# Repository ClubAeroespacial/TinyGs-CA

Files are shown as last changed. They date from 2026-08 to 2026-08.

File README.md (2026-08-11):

# Placa ESP32-C3 + SX1278 (LoRa 433 MHz) — Version2

Bring-up y validación de la revisión **Version2** de la placa.
Módulos: **ESP32-C3-WROOM-02-N4** (4 MB) + módulo **SX1278** de 433 MHz con conector u.FL.

**Estado: hardware validado.** 5 unidades fabricadas (3 + 2), todas funcionando.
Enlace LoRa bidireccional confirmado entre dos placas.

---

## Pinout

Verificado de dos formas independientes: extraído del netlist de KiCad
(`Version2.kicad_pcb`) y confirmado con firmware que corre en la placa.

| Señal | GPIO | Pad del módulo | Nota |
|---|---|---|---|
| LoRa SCK | **10** | 10 | |
| LoRa MISO | **6** | 5 | |
| LoRa MOSI | **7** | 6 | |
| LoRa NSS | **8** | 7 | strapping pin — ver ERRATA #4 |
| LoRa RESET | **5** | 4 | |
| LoRa DIO0 | **4** | 3 | conectado, permite usar interrupciones |
| UART TX | **21** | 12 | compartido con el LED — ver ERRATA #1 |
| UART RX | **20** | 11 | |
| Botón RESET | EN | 2 | |
| Botón BOOT | **0** | 18 | no es strapping pin — ver ERRATA #2 |
| Pull-up 10k (R10) | 2 | 16 | strapping, correcto |
| Pull-up 10k (R11) | 8 | 7 | strapping, correcto |

**GPIO libres:** 1, 3, 9, 18, 19
**DIO1–DIO5 del SX1278:** sin conectar

```cpp
#define PIN_SCK   10
#define PIN_MISO   6
#define PIN_MOSI   7
#define PIN_NSS    8
#define PIN_RST    5
#define PIN_DIO0   4
```

---

## Estado de validación

| Qué | Estado | Evidencia |
|---|---|---|
| Regulador 3.3 V (AMS1117) | OK | 3.3 V medidos, sin cortos |
| Arranque del ESP32-C3 | OK | mensaje de la ROM en UART |
| Flash 4 MB | OK | `flash-id` y sketches corriendo |
| UART bidireccional | OK | consola + flasheo exitoso |
| Modo programación | OK | `boot:0x5 (DOWNLOAD(USB/UART0/1))` |
| WiFi + estabilidad de fuente | OK | 6 redes, sin brownout en el pico de ~350 mA |
| SPI hacia el SX1278 | OK | `RegVersion = 0x12` estable |
| **Enlace LoRa bidireccional** | **OK** | PING/PONG entre 2 placas y test 14 del banco |
| **Test de producción completo** | **OK** | **14/14** en las unidades probadas |

Valores de referencia de placa sana: WiFi **-48 a -51 dBm** con 10-14 redes,
piso de ruido LoRa **-123 dBm**, frecuencia por defecto **434.0 MHz**.
Ver la tabla completa en [ERRATA.md](ERRATA.md).

### Todavía sin validar

- Alcance real (requiere antenas u.FL → SMA, aún no disponibles)
- Consumo en régimen y a batería
- Comportamiento térmico bajo carga sostenida

> **Nota sobre el -124 dBm:** la sensibilidad del SX1278 en SF7/BW125 es -123 dBm.
> El enlace funcionó **en el límite físico del chip**, sin antena y a 2 dBm, con
> ~8% de paquetes exitosos. Eso no es una falla: es el resultado esperado con los
> conectores u.FL al aire. Con antenas se espera -40 a -50 dBm a corta distancia.

---

## Cómo flashear

El programador usado es un **PL2303 sin DTR/RTS**, así que el modo descarga se
entra a mano.

### Cableado (TX y RX van cruzados)

```
PL2303              J2
------              --------------
GND     --------->  GND   (pin 1)
+5V     --------->  5V    (pin 2)
RXD     <---------  TX    (pin 3)
TXD     --------->  RX    (pin 4)
(nada)              RST   (pin 5)
(nada)              DTR   (pin 6)
```

### Configuración de Arduino IDE

| Opción | Valor |
|---|---|
| Board | ESP32C3 Dev Module |
| **USB CDC On Boot** | **Disabled** |
| Flash Mode | DIO |
| Flash Size | 4MB (32Mb) |
| Upload Speed | 921600 (probado y estable) |

### Secuencia

```
1. Mantener BOOT apretado
2. Apretar y soltar RESET
3. Soltar BOOT
4. Verificar en el monitor: boot:0x... (DOWNLOAD(USB/UART0/1))
5. Cerrar el Monitor Serie
6. Upload
7. Apretar RESET a mano (no hay RTS conectado)
```

**Indicador infalible:** el `boot:0x...` del mensaje de arranque.
`DOWNLOAD` = listo para flashear. `SPI_FAST_FLASH_BOOT` = no entraste.

---

## Sketches

| Carpeta | Qué prueba | Cuándo usarlo |
|---|---|---|
| `00_test_produccion/` | **14 pruebas automáticas con veredicto APROBADA / RECHAZADA** y línea CSV para planilla | **El de todos los días.** Es el banco de pruebas del lote. Ver la calibración de umbrales en ERRATA.md antes de correr una tanda |
| `04_test_lucas/` | Lee `RegVersion` del SX1278 por SPI | Primer test de una placa nueva si querés algo mínimo. 70 líneas, sin librerías |
| `01_smoke_test/` | CPU, flash, UART, LED, escaneo de WiFi | Validación general. El escaneo de WiFi es el que fuerza el pico de 350 mA y detecta problemas de fuente |
| `05_buscar_led/` | Versión corta del anterior | Cuando solo querés el estrés de fuente sin todo lo demás |
| `02_scan_sx1278/` | Encuentra los pines SPI por fuerza bruta | Si alguna vez hay una revisión nueva y no se conoce el pinout. Con el comando `v` verifica un pinout conocido en 2 segundos |
| `03_lora_pingpong/` | **Enlace de radio real entre 2 placas** | El único test que valida el amplificador, el cristal y el camino de antena |

> `04_test_lucas.ino` está **sin modificar**, tal como fue escrito originalmente.
> Se conserva así a propósito: es la referencia contra la que se comparó todo lo demás.

### Ping-pong: cómo se corre

El **mismo sketch** va en las dos placas. Las dos arrancan como RESPONDEDOR.
En la que tiene consola se manda `a` y pasa a EMISOR.

```
a  -> pasar a EMISOR        s  -> estadísticas
b  -> pasar a RESPONDEDOR   r  -> medir piso de ruido
t<n> -> potencia TX (2-17)  f<n> -> spreading factor (7-12)
d  -> cazar el pin DIO0
```

**Sin antena: 2 dBm y las placas a 5-10 cm.** No subir la potencia: el PA se
degrada transmitiendo contra un circuito abierto, y la degradación es silenciosa.

---

## Documentos

- **[ERRATA.md](ERRATA.md)** — los 7 defectos encontrados y qué cambiar en la v2
- **[00_GUIA_BRINGUP.md](00_GUIA_BRINGUP.md)** — guía completa de bring-up con mediciones
- **[PASOS_TEST_LUCAS.md](PASOS_TEST_LUCAS.md)** — procedimiento paso a paso con hitos

---

## Pendientes

- [ ] Comprar pigtails u.FL → SMA y antenas de 433 MHz (×5)
- [ ] Medir alcance real al aire libre
- [ ] Adaptador USB-TTL con DTR/RTS (CP2102 o CH340) para reset automático
- [ ] Regenerar los gerbers desde Version2 — ver ERRATA #7
- [ ] Aplicar los cambios de ERRATA.md a la v3

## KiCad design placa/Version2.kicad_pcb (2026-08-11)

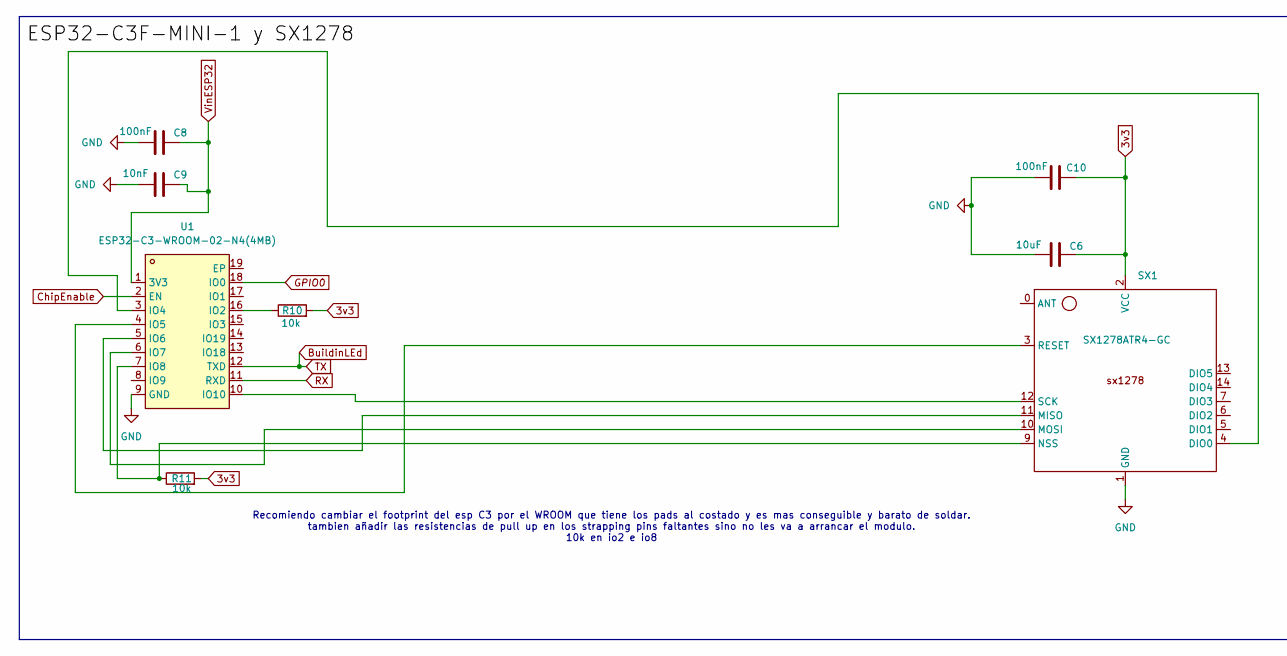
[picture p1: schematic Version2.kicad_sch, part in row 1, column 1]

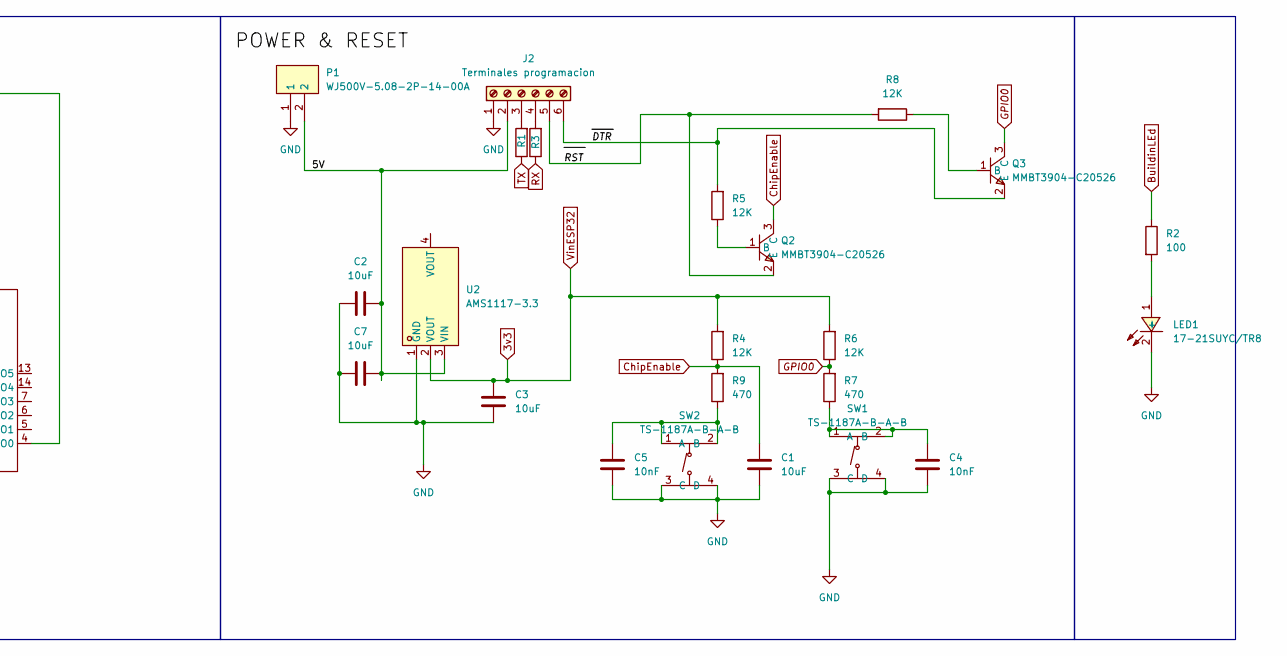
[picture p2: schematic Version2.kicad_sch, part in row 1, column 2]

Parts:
C1, C2, C3, C6, C7: 10uF; C_0805_2012Metric
C4, C5, C9: 10nF; C_0402_1005Metric
C8, C10: 100nF; C_0402_1005Metric
J2: Terminales programacion; PinHeader_1x06_P2.54mm_Vertical; LCSC part C42431807
LED1: 17-21SUYC/TR8; LED_0805_2012Metric; LCSC Part C2296
P1: WJ500V-5.08-2P-14-00A; CONN-TH_2P-P5.00_WJ500V-5.08-2P; LCSC Part C8465
Q2, Q3: MMBT3904-C20526; SOT-23-3_L2.9-W1.3-P1.90-LS2.4-BR; LCSC Part C20526
R1, R3: 10; R_0603_1608Metric
R2: 100; R_0603_1608Metric
R4, R5, R6, R8: 12K; R_0603_1608Metric
R7, R9: 470; R_0603_1608Metric
R10, R11: 10k; R_0603_1608Metric; LCSC Part C31850
SW1, SW2: TS-1187A-B-A-B; SW-SMD_4P-L5.1-W5.1-P3.70-LS6.5-TL_H1.5; LCSC Part C318884
SX1: SX1278ATR4-GC; Sin título; LCSC part C42381680
U1: ESP32-C3-WROOM-02-N4(4MB); BULETM-SMD_ESPRESSIF_ESP32-C3-WROOM-02-N4-4MB; LCSC Part C2934560
U2: AMS1117-3.3; SOT-223-3_L6.5-W3.4-P2.30-LS7.0-BR; LCSC Part C6186

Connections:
3v3: C3.2, C6.2, C8.2, C9.2, C10.2, R4.2, R6.2, R10.2, R11.2, SX1.2 (VCC), U1.1 (3V3), U2.2 (VOUT)
/5V: C2.2, C7.2, J2.2, P1.2, U2.3 (VIN)
/DTR: J2.6, Q3.2 (E), R5.2
/RST: J2.5, Q2.2 (E), R8.2
BuildinLEd: R1.1, R2.1, U1.12 (TXD)
ChipEnable: C1.1, Q2.3 (C), R4.1, R9.2, U1.2 (EN)
GND: C1.2, C2.1, C3.1, C4.2, C5.2, C6.1, C7.1, C8.1, C9.1, C10.1, J2.1, LED1.2 (-), P1.1, SW1.3 (C), SW1.4 (D), SW2.3 (C), SW2.4 (D), SX1.1 (GND), U1.9 (GND), U2.1 (GND)
GPIO0: Q3.3 (C), R6.1, R7.2, U1.18 (IO0)
unnamed: J2.3, R1.2
unnamed: J2.4, R3.2
unnamed: LED1.1 (+), R2.2
unnamed: Q2.1 (B), R5.1
unnamed: Q3.1 (B), R8.1
unnamed: C4.1, R7.1, SW1.1 (A), SW1.2 (B)
unnamed: C5.1, R9.1, SW2.1 (A), SW2.2 (B)
unnamed: SX1.4 (DIO0), U1.3 (IO4)
unnamed: SX1.11 (MISO), U1.5 (IO6)
unnamed: SX1.10 (MOSI), U1.6 (IO7)
unnamed: R11.1, SX1.9 (NSS), U1.7 (IO8)
unnamed: SX1.3 (RESET), U1.4 (IO5)
unnamed: SX1.12 (SCK), U1.10 (IO10)
unnamed: R10.1, U1.16 (IO2)
RX: R3.1, U1.11 (RXD)

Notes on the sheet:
Recomiendo cambiar el footprint del esp C3 por el WROOM que tiene los pads al costado y es mas conseguible y barato de soldar. tambien añadir las resistencias de pull up en los strapping pins faltantes sino no les va a arrancar el modulo. 10k en io2 e io8

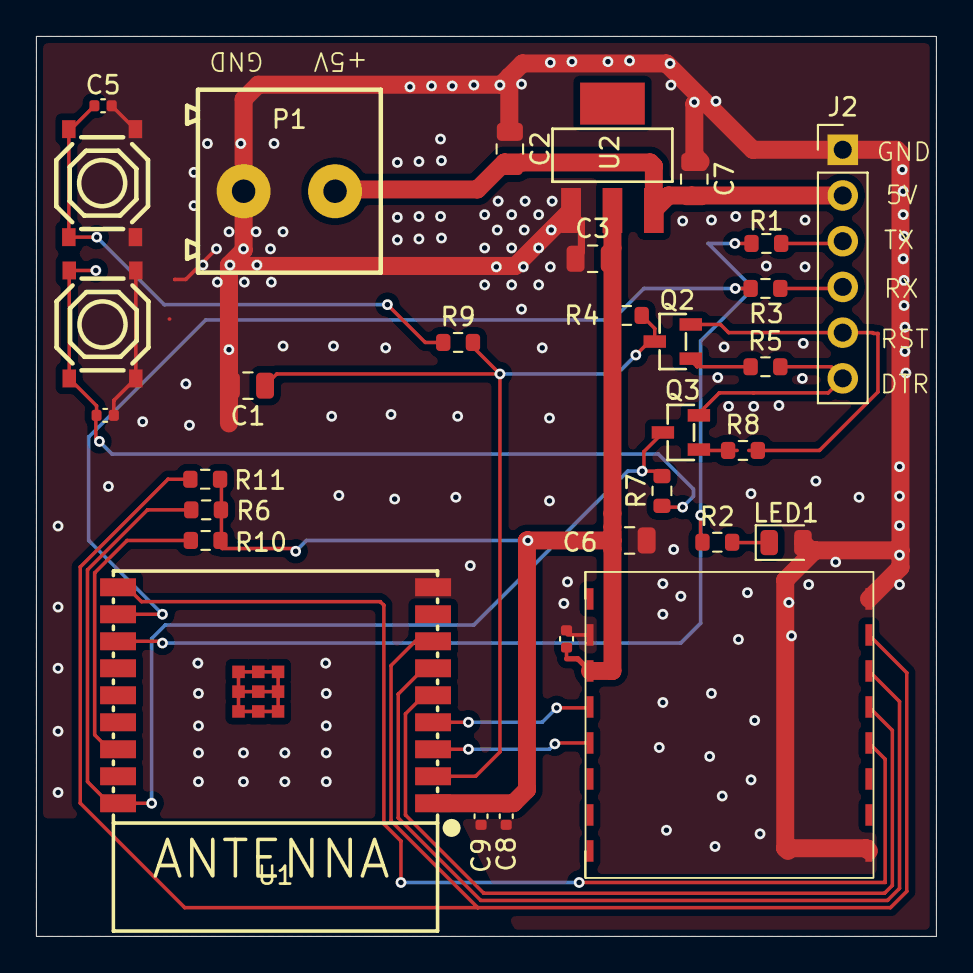
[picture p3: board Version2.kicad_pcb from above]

Board: 2 copper layers, 50.0 x 50.0 mm, 31 parts (0 on the bottom side), 23 nets.

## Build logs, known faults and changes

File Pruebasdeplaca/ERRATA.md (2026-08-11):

# ERRATA — Version2

Defectos encontrados durante el bring-up, con la evidencia que los sustenta y el
cambio concreto para la próxima revisión.

**Ninguno impide que la placa funcione.** Las unidades pasan el test de
producción **14/14**, incluido el enlace de radio verificado entre dos placas.
Esto es la lista de lo que hay que arreglar antes de fabricar de nuevo.

Severidad: **A** = arreglar sí o sí · **B** = arreglar si se puede · **C** = cosmético

| # | Defecto | Sev | Estado |
|---|---|---|---|
| 1 | LED sobre la línea TX del UART | **A** | Confirmado |
| 2 | GPIO9 sin conectar; botón BOOT a GPIO0 | **A** | Confirmado + anomalía abierta |
| 3 | Pad térmico (EP) sin conectar a masa | **B** | Confirmado, impacto menor al estimado |
| 4 | NSS sobre un strapping pin | **B** | Confirmado |
| 5 | Desacoplo insuficiente (C9) | **B** | Confirmado, sin impacto medible |
| 6 | Sin protección en la alimentación | **B** | Confirmado |
| 7 | Carpeta `production/` desactualizada | **A** | Operativo |

---

## #1 — El LED está sobre la línea TX del UART · **A**

**Qué pasa.** La red `BuildinLEd` quedó conectada al pad 12 del módulo, que es
**TXD (GPIO21)**. Cadena completa: `GPIO21 → R2 (100 Ω) → LED1 → GND`.

**Consecuencia.** El TX de un UART reposa en alto, así que el LED queda
**encendido en forma permanente** y titila cuando sale data serie.
**No se puede controlar por software**: manejarlo destruye la consola.
Además le chupa ~13 mA continuos a una línea de señal, lo cual es relevante
si el producto alguna vez va a batería.

**Evidencia.**
```
U1 pad 12 (TXD_12) -> net "BuildinLEd"
R2.1 -> BuildinLEd    R2.2 -> Net-(LED1-+)    LED1.1 -> Net-(LED1-+)    LED1.2 -> GND
```
El mismo error existía en la revisión anterior (`PrimerPrueba`):
`U3 pad 31 (IO21/TXD) -> BUILDINLED`. Se arrastra desde el primer prototipo.

**Causa raíz.** En el esquemático, la etiqueta global `BuildinLEd` quedó colocada
encima del cable de TX. KiCad no lo reporta como error: es una red válida con dos
nombres.

**Fix v3.** Mover la red a **GPIO3** (pad 15, libre). Verificar con "Resaltar red"
que la etiqueta no toque ningún otro cable.

> **Defecto de ensamblado adicional, confirmado:** en las placas recibidas el LED
> está montado con la polaridad invertida, así que ni siquiera enciende.
> **No repararlo:** aunque se corrija la orientación sigue sin ser controlable,
> y no justifica calentar la placa. Se resuelve en la v3 con el cambio de red.

---

## #2 — GPIO9 sin conectar; el botón BOOT va a GPIO0 · **A**

**Qué pasa.** El pin de arranque del ESP32-C3 es **GPIO9**, y está sin conectar.
El botón BOOT (SW1) y el transistor de auto-reset (Q3) van a **GPIO0**, que en el
C3 es un GPIO común sin ninguna función de strapping.

**Evidencia del netlist.**
```
U1 pad 8  (IO9_8)  -> unconnected-(U1-IO9-Pad8)
U1 pad 18 (IO0_18) -> net "GPIO0"   (SW1 + Q3 + R6)
```

### La anomalía, con evidencia nueva

Según los archivos ese botón **no debería** poder meter el chip en modo descarga.
En la práctica **funciona**, de forma repetible, en las 5 placas:
`boot:0x5 (DOWNLOAD(USB/UART0/1))` después de la secuencia BOOT+RESET.

Y apareció un dato más, en dirección opuesta: el firmware de test lee `GPIO0`
para elegir el modo baliza, y **apretando ese mismo botón el pin nunca baja**.
Hubo que agregar un comando por serie porque el botón no se detectaba.

Las dos observaciones juntas apuntan a lo mismo: **el botón se comporta como si
estuviera físicamente en GPIO9, no en GPIO0.** Eso explicaría que el modo
descarga funcione y que `digitalRead(0)` no lo vea.

> **Cuidado con esta conclusión.** La prueba del botón puede haber corrido sobre
> un firmware viejo, así que la evidencia está contaminada. No darla por cerrada.

**Cómo se resuelve, definitivo, 2 minutos.** Multímetro en continuidad, con el
botón SW1 apretado:

| Una punta | Otra punta | Si pita |
|---|---|---|
| pata de SW1 | **pad 8** del módulo (IO9) | El botón está en GPIO9. El netlist no refleja la placa |
| pata de SW1 | **pad 18** del módulo (IO0) | El netlist tiene razón y la anomalía sigue abierta |

**Por qué importa igual.** Lo que funciona sin que se sepa por qué es lo que
después deja de funcionar sin que se sepa por qué: otro lote de módulos, otra
revisión de silicio, otra temperatura.

**Fix v3.** Cablear SW1 y el colector de Q3 a **GPIO9** (pad 8) de forma explícita.
Renombrar la red `GPIO0` a **`BOOT_IO9`** — un nombre que miente cuesta horas.

---

## #3 — El pad térmico (EP) del ESP32 no está conectado a masa · **B**

> **Corregido respecto de la versión anterior de este documento.** Estaba
> clasificado como **A** por sospecha de que degradaba el RF. **Los datos no lo
> respaldan** y baja a **B**.

**Qué pasa.** El pad 19 (EP) del módulo, que es su pad de masa y disipación,
quedó sin red. El módulo se aterriza únicamente por el pad 9.

**Evidencia.**
```
U1 pad 19 (EP_19) -> unconnected-(U1-EP-Pad19)
```

**Impacto real: menor al estimado.** La hipótesis inicial era que explicaba un
WiFi flojo (-71 dBm en la primera medición). Las corridas posteriores dieron de
forma consistente **-48 a -51 dBm con 10 a 14 redes**, que son valores sanos.
El -71 fue distancia u orientación, no la placa. El piso de ruido del SX1278
también da normal: **-123 dBm**.

**Sigue siendo un defecto** de disipación y de retorno de masa, y hay que
arreglarlo. Pero no está limitando el rendimiento actual.

**Fix v3.** Conectar EP a GND con un array de vías térmicas (mínimo 4).

---

## #4 — NSS del SX1278 sobre un strapping pin · **B**

**Qué pasa.** `NSS` está en **GPIO8**, que debe estar en ALTO al soltar el reset o
el ESP32-C3 no arranca.

**Por qué funciona igual.** NSS reposa en alto (que es justo lo que GPIO8 necesita)
y R11 (10 kΩ) lo mantiene arriba antes de que el firmware tome el pin.

**Por qué es frágil.** No queda margen. Cualquier cosa que tire GPIO8 a masa
durante el reset —una punta de multímetro apoyada, un módulo LoRa con la entrada
dañada, flux conductivo— deja la placa sin arrancar, con un síntoma que parece un
ESP32 muerto y no lo es.

**Fix v3.** Mover NSS a **GPIO1** (pad 17, libre).

---

## #5 — Desacoplo insuficiente en el ESP32 · **B**

**Qué pasa.** `C9 = 10 nF` donde la nota de aplicación de Espressif pide **10 µF**.
Casi seguro un typo. El módulo queda con 100 nF + 10 nF y sin capacitor de masa.

**Impacto medido: ninguno.** El escaneo de WiFi (pico de ~350 mA) corrió completo
en todas las placas probadas, sin brownout ni resets. El bulk del regulador
(C3, 10 µF) alcanza a cubrirlo.

**Fix v3.** `C9 → 10 µF`, ubicado lo más cerca posible del pad 1 del módulo.

---

## #6 — Sin protección en la entrada de alimentación · **B**

**Qué pasa.** `P1` entra directo al AMS1117. No hay protección contra inversión de
polaridad ni contra sobretensión.

**Consecuencia.** Un cable invertido mata el regulador y probablemente lo que
venga después. En una bornera a tornillo que va a manipular gente distinta, y con
30 unidades en circulación, es cuestión de tiempo.

**Fix v3.** Schottky en serie (SS34 o similar) o un P-MOSFET para no perder los
0.3 V de caída, más un TVS a masa. Y marca de polaridad en la serigrafía.

---

## #7 — La carpeta `production/` es de la revisión vieja · **A (operativo)**

**Qué pasa.** `production/` contiene los gerbers y el netlist IPC de
**`PrimerPrueba`**, la revisión anterior, que usaba el footprint
**ESP32-C3-MINI-1 de 53 pads**. Las placas actuales llevan un
**WROOM-02 de 19 pads**: footprints físicamente incompatibles.

**Evidencia.** En `production/netlist.ipc` el ESP32 figura como `U3` con 53 pads,
y no existen R10 ni R11 (los pull-ups de strapping que sí tiene Version2).

**Consecuencia.** Si se manda esa carpeta a fabricar, llegan placas para un módulo
que no se tiene. Con un pedido de 30 unidades, es un error caro.

**Fix inmediato.** Borrar `production/` o regenerar los gerbers desde
`Version2.kicad_pcb` **antes de pedir cualquier cosa**. Ya está en `.gitignore`.

---

# Datos de referencia del lote

Valores de placas conocidas buenas. Sirven como línea de base: en un lote de 30,
**lo que importa es la dispersión, no el valor absoluto.** Una unidad que se sale
del rango tiene un problema aunque pase todos los umbrales.

| Medición | Rango observado | Qué significa salirse |
|---|---|---|
| WiFi, mejor RSSI | **-48 a -51 dBm** | 15 dB peor que el resto → antena PCB tapada o soldadura del módulo |
| WiFi, redes vistas | 10 a 14 | Muy pocas → mismo problema |
| Piso de ruido LoRa | **-123 dBm** | Muy alto → interferencia o ruido de fuente. Muy bajo → front-end dañado |
| Frecuencia por defecto | ~434.0 MHz | Otra cosa → módulo de otra banda o que no resetea |
| Rail de 3.3 V | 3.25 – 3.35 V | Regulador |
| Enlace con la baliza | ver abajo | — |

## Calibración del banco de pruebas

**Sin antenas, la distancia a la baliza domina el resultado.** Medido:

| Distancia | RSSI | Utilidad |
|---|---|---|
| ~50 cm | **-124 dBm** | Inservible. Está en el límite de sensibilidad del chip (-123 dBm en SF7/BW125): ~8% de paquetes pasan, y una placa buena falla al azar |
| 5 a 10 cm | ~-105 dBm | Usable |

**Procedimiento antes de correr un lote:**

1. Poner la baliza a 5-10 cm y dejarla fija ahí
2. Correr el test en varias placas ya validadas y anotar el RSSI del enlace
3. Poner `RSSI_ENLACE_MIN` unos **10 dB por debajo del peor** de esos valores
4. Verificar que el detalle diga **`1i`** (un solo intento). Si necesita más de
   uno, el enlace está al límite y el test no discrimina

Con el umbral pegado a la sensibilidad, el test mide suerte, no calidad.
Una placa con el amplificador degradado da 15 a 20 dB peor que una sana: **ese**
es el margen que hay que poder detectar.

> Cuando lleguen los pigtails u.FL → SMA y las antenas, repetir la calibración.
> Los números van a mejorar mucho y los umbrales hay que rehacerlos.

---

# Lista de cambios para la v3

## Obligatorios

- [ ] `BuildinLEd`: GPIO21 (TX) → **GPIO3**
- [ ] Botón BOOT y Q3: GPIO0 → **GPIO9**. Renombrar la red a `BOOT_IO9`
- [ ] Pad térmico EP → **GND** con vías térmicas
- [ ] Regenerar los gerbers desde Version2

## Recomendados

- [ ] NSS: GPIO8 → **GPIO1**
- [ ] `C9`: 10 nF → **10 µF**
- [ ] Schottky + TVS en `P1`, y marca de polaridad en la serigrafía
- [ ] Keep-out de la antena PCB: sin cobre en ninguna capa

## Mejoras

- [ ] **Conector USB-C en GPIO18/19.** El ESP32-C3 tiene USB-Serial-JTAG nativo y
      esos dos pines están libres. Elimina el adaptador TTL para siempre. Con 30
      unidades a flashear, esto solo ya paga el rediseño
- [ ] Puntos de test (pads de 1 mm) en 3V3, GND, EN, IO9 y el bus SPI
- [ ] Serigrafía que diga cuál botón es **BOOT** y cuál **RESET**
- [ ] Evaluar reemplazar el AMS1117 por un LDO de bajo Iq o un buck, si va a
      batería (el AMS1117 consume ~5 mA solo por existir)

## Pinout propuesto para la v3

| Señal | GPIO actual | GPIO propuesto |
|---|---|---|
| LoRa SCK | 10 | 10 |
| LoRa MISO | 6 | 6 |
| LoRa MOSI | 7 | 7 |
| LoRa NSS | **8** | **1** |
| LoRa RESET | 5 | 5 |
| LoRa DIO0 | 4 | 4 |
| LED | **21 (TX)** | **3** |
| Botón BOOT | **0** | **9** |
| USB D− / D+ | — | **18 / 19** |

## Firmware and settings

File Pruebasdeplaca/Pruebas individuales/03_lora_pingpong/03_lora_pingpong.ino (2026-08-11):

/*
 * ============================================================================
 *  TEST 3 - ENLACE LoRa REAL ENTRE PLACAS (ping / pong)
 *  ESP32-C3-WROOM-02 + SX1278 (Ra-02) @ 433 MHz
 * ============================================================================
 *
 *  >>>>>>>>>>>>>>>>>>>>>>>  LEER ANTES DE ENCHUFAR  <<<<<<<<<<<<<<<<<<<<<<<<<
 *
 *  NUNCA TRANSMITAS SIN ANTENA. La potencia reflejada puede danar el
 *  amplificador del SX1278. Antes de correr esto, cada placa que vaya a
 *  transmitir necesita algo en el pad ANT:
 *
 *      - un cable rigido de 16.4 cm  (lambda/4 a 433 MHz), o
 *      - un pigtail IPEX -> SMA con antena de 433 MHz
 *
 *  Arranca con potencia baja (2 dBm). Con las placas a 50 cm eso sobra.
 *  Subir la potencia con las placas pegadas satura el receptor y te da
 *  peores resultados, no mejores.
 *
 *  >>>>>>>>>>>>>>>>>>>>>>>>>>>>>>>>>>>>>>>>>>>>>>>>>>>>>>>>>>>>>>>>>>>>>>>>>
 *
 *  LIBRERIA NECESARIA:
 *    Arduino IDE -> Herramientas -> Administrar Bibliotecas -> buscar "LoRa"
 *    -> instalar "LoRa" de Sandeep Mistry
 *
 *  COMO SE USA (con un solo programador TTL, que es tu caso):
 *    1. Flashea este MISMO sketch en las 3 placas.
 *    2. Todas arrancan como RESPONDEDOR: escuchan y contestan solas,
 *       sin necesidad de serial. El LED parpadea con cada paquete recibido.
 *    3. Deja el TTL conectado a UNA sola placa y manda 'a' por serial:
 *       esa pasa a EMISOR y empieza a mandar PING.
 *    4. Mira las estadisticas en el monitor.
 *
 *  ARDUINO IDE: Board = ESP32C3 Dev Module | USB CDC On Boot = Disabled | 115200
 * ============================================================================
 */

#include <SPI.h>
#include <LoRa.h>

// ############################################################################
// #  PINOUT REAL - extraido del codigo de Lucas que ya anda en la placa      #
// ############################################################################
#define PIN_SCK     10
#define PIN_MISO    6
#define PIN_MOSI    7
#define PIN_NSS     8      // OJO: GPIO8 es strapping pin. Ver nota abajo.
#define PIN_RST     5
#define PIN_DIO0    4      // CONFIRMADO en el netlist de KiCad (SX1.DIO0 -> U1 IO4)

// EL LED NO SE PUEDE USAR. Esta cableado a GPIO21, que es el TX del UART.
// Como el TX reposa en alto, el LED esta PRENDIDO FIJO siempre y titila cuando
// sale data serie. No hay forma de controlarlo sin romper la consola.
#define PIN_LED     -1     // dejalo en -1. No lo cambies.
// ############################################################################
//
// NOTA SOBRE GPIO8 = NSS
// GPIO8 es un strapping pin del ESP32-C3: tiene que estar en ALTO al soltar el
// reset o el chip no arranca. Funciona porque:
//   - NSS reposa en alto (que es justo lo que GPIO8 necesita)
//   - R11 (10k a 3V3) lo mantiene arriba antes de que el ESP32 lo maneje
// Pero es fragil: cualquier cosa que tire GPIO8 a masa durante el reset deja la
// placa sin arrancar. GPIO4 y GPIO9 estan libres. Para la v2, move NSS a GPIO4.
//
// ############################################################################

#define BAUD          115200
#define FRECUENCIA    433E6      // SX1278 = banda de 433 MHz
#define SYNC_WORD     0x34       // cualquier valor != 0x34 default; que sea igual en las 3
#define TX_POWER_INI  2          // dBm. Rango PA_BOOST: 2..17
#define PERIODO_PING  1500       // ms entre PINGs
#define TIMEOUT_PONG  1200       // ms de espera de respuesta

enum Rol { RESPONDEDOR, EMISOR };
Rol rol = RESPONDEDOR;

uint16_t miId = 0;
uint32_t seq = 0;
int txPower = TX_POWER_INI;
int sf = 7;

// estadisticas (solo utiles en modo EMISOR)
uint32_t enviados = 0, contestados = 0;
long rssiAcum = 0; int rssiN = 0;
int rssiMejor = -200, rssiPeor = 0;

unsigned long tUltimoPing = 0;
bool esperandoPong = false;
unsigned long tEnvio = 0;

// ----------------------------------------------------------------- utilidades

void blink(int n, int ms) {
  if (PIN_LED < 0) return;
  pinMode(PIN_LED, OUTPUT);
  for (int i = 0; i < n; i++) {
    digitalWrite(PIN_LED, HIGH); delay(ms);
    digitalWrite(PIN_LED, LOW);  delay(ms);
  }
}

void enviar(const String &msg) {
  LoRa.beginPacket();
  LoRa.print(msg);
  LoRa.endPacket();          // bloqueante: vuelve cuando termino el TX
  LoRa.receive();            // vuelvo a modo escucha
}

String campo(const String &s, int n) {
  int ini = 0, cnt = 0;
  for (int i = 0; i <= (int)s.length(); i++) {
    if (i == (int)s.length() || s.charAt(i) == ';') {
      if (cnt == n) return s.substring(ini, i);
      cnt++;
      ini = i + 1;
    }
  }
  return "";
}

// ------------------------------------------------------- cazador de DIO0
//
// DIO0 no aparece en el codigo de Lucas, asi que no sabemos en que pin esta.
// Este cazador es 100% SEGURO: pone los pines candidatos como ENTRADA y solo
// los lee. Nunca maneja nada, asi que no puede pelearse con una salida del
// SX1278 ni con nada mas.
//
// Como funciona: DIO0 se pone en ALTO cuando el radio termina de recibir un
// paquete (RxDone) y vuelve a BAJO cuando parsePacket() limpia las banderas.
// Muestreamos justo antes de parsePacket() en cada vuelta del loop, asi que
// atrapamos ese pulso.

const int DIO_CAND[] = {0, 1, 2, 3, 4, 9, 18, 19};   // los que quedan libres
const int N_DIO = sizeof(DIO_CAND) / sizeof(DIO_CAND[0]);

bool cazandoDio0 = false;
uint16_t dioVistoAlto = 0;    // bit por candidato
uint32_t dioMuestras = 0;

void iniciarCazaDio0() {
  for (int i = 0; i < N_DIO; i++) pinMode(DIO_CAND[i], INPUT);
  dioVistoAlto = 0;
  dioMuestras = 0;
  cazandoDio0 = true;
  Serial.println();
  Serial.println(F("CAZA DE DIO0 ACTIVADA (solo lectura, riesgo cero)."));
  Serial.println(F("Necesita trafico: pone esta placa o la otra a mandar PING."));
  Serial.println(F("Despues de unos 20 paquetes, manda 'd' otra vez para ver el resultado."));
}

inline void muestrearDio() {
  if (!cazandoDio0) return;
  for (int i = 0; i < N_DIO; i++) {
    if (digitalRead(DIO_CAND[i]) == HIGH) dioVistoAlto |= (1 << i);
  }
  dioMuestras++;
}

void reporteDio0() {
  Serial.println();
  Serial.println(F("=============== RESULTADO CAZA DE DIO0 ==============="));
  Serial.printf("  Muestras tomadas: %lu\n", (unsigned long)dioMuestras);
  Serial.println();
  int candidatos = 0;
  for (int i = 0; i < N_DIO; i++) {
    bool alto = dioVistoAlto & (1 << i);
    Serial.printf("  GPIO %-2d  ->  %s\n", DIO_CAND[i],
                  alto ? "estuvo en ALTO   <<< candidato" : "siempre en bajo");
    if (alto) candidatos++;
  }
  Serial.println();
  if (candidatos == 0) {
    Serial.println(F("  Ningun pin se movio. O DIO0 no esta conectado en esta placa,"));
    Serial.println(F("  o no hubo suficiente trafico. Genera mas paquetes y repeti."));
  } else if (candidatos == 1) {
    Serial.println(F("  Un solo candidato: ese es DIO0 con mucha probabilidad."));
    Serial.println(F("  Cargalo en PIN_DIO0 arriba y confirmalo contra el esquematico."));
  } else {
    Serial.println(F("  Varios pines en alto. Algunos tienen pull-up (GPIO2 con R10,"));
    Serial.println(F("  GPIO9 interno, GPIO0 con R6): esos son falsos positivos, siempre"));
    Serial.println(F("  estan altos. El que te interesa es uno que NO tenga pull-up."));
    Serial.println(F("  La forma definitiva de saberlo sigue siendo el esquematico."));
  }
  Serial.println(F("======================================================"));
}

// ---------------------------------------------------------------------- ayuda

void ayuda() {
  Serial.println();
  Serial.println(F("------------------------- COMANDOS -------------------------"));
  Serial.println(F("  a     -> pasar a EMISOR (manda PING cada 1.5 s)"));
  Serial.println(F("  b     -> pasar a RESPONDEDOR (escucha y contesta)"));
  Serial.println(F("  s     -> mostrar estadisticas"));
  Serial.println(F("  z     -> borrar estadisticas"));
  Serial.println(F("  t<n>  -> potencia TX en dBm, 2 a 17.  ej: t2   t17"));
  Serial.println(F("  f<n>  -> spreading factor, 7 a 12.    ej: f7   f12"));
  Serial.println(F("  r     -> medir piso de ruido durante 3 s"));
  Serial.println(F("  d     -> cazar el pin DIO0 (1a vez arranca, 2a vez muestra)"));
  Serial.println(F("  ?     -> esta ayuda"));
  Serial.println(F("------------------------------------------------------------"));
}

void estadisticas() {
  Serial.println();
  Serial.println(F("=================== ESTADISTICAS ==================="));
  Serial.printf("  Mi ID .................. %04X\n", miId);
  Serial.printf("  Rol .................... %s\n", rol == EMISOR ? "EMISOR" : "RESPONDEDOR");
  Serial.printf("  Frecuencia ............. %.1f MHz\n", FRECUENCIA / 1e6);
  Serial.printf("  Potencia TX ............ %d dBm\n", txPower);
  Serial.printf("  Spreading factor ....... SF%d\n", sf);
  Serial.println();
  Serial.printf("  PING enviados .......... %lu\n", (unsigned long)enviados);
  Serial.printf("  PONG recibidos ......... %lu\n", (unsigned long)contestados);
  if (enviados > 0) {
    float perdida = 100.0 * (enviados - contestados) / (float)enviados;
    Serial.printf("  Perdida de paquetes .... %.1f %%\n", perdida);
    if (perdida < 2)       Serial.println(F("     -> enlace EXCELENTE"));
    else if (perdida < 10) Serial.println(F("     -> enlace bueno"));
    else if (perdida < 30) Serial.println(F("     -> enlace flojo: mira antena y potencia"));
    else                   Serial.println(F("     -> enlace MALO: revisa antenas y distancia"));
  }
  if (rssiN > 0) {
    Serial.println();
    Serial.printf("  RSSI promedio .......... %ld dBm\n", rssiAcum / rssiN);
    Serial.printf("  RSSI mejor / peor ...... %d / %d dBm\n", rssiMejor, rssiPeor);
    Serial.println();
    Serial.println(F("  Referencia de RSSI:"));
    Serial.println(F("    -30 a -60  placas muy cerca, normal en el banco"));
    Serial.println(F("    -60 a -90  enlace sano"));
    Serial.println(F("    -90 a -110 al limite"));
    Serial.println(F("    peor a -120 no vas a recibir nada"));
  }
  Serial.println(F("===================================================="));
}

void pisoDeRuido() {
  Serial.println();
  Serial.println(F("Midiendo piso de ruido 3 s (sin transmitir)..."));
  LoRa.receive();
  int minR = 0, maxR = -200; long acum = 0; int n = 0;
  unsigned long t0 = millis();
  while (millis() - t0 < 3000) {
    int r = LoRa.rssi();
    if (r < minR) minR = r;
    if (r > maxR) maxR = r;
    acum += r; n++;
    delay(10);
  }
  Serial.printf("  Piso de ruido: min %d / prom %ld / max %d dBm  (%d muestras)\n",
                minR, n ? acum / n : 0, maxR, n);
  Serial.println(F("  Tipico: entre -110 y -125 dBm. Si esta mucho mas arriba,"));
  Serial.println(F("  tenes interferencia o ruido de la propia fuente switching."));
}

// ---------------------------------------------------------------------- setup

void setup() {
  Serial.begin(BAUD);
  delay(400);

  Serial.println();
  Serial.println();
  Serial.println(F("############################################################"));
  Serial.println(F("#   TEST 3 - ENLACE LoRa (ping / pong)                      #"));
  Serial.println(F("############################################################"));
  Serial.println();
  Serial.println(F("  !! SIN ANTENA NO TRANSMITAS !!"));
  Serial.println();

  uint64_t mac = ESP.getEfuseMac();
  miId = (uint16_t)(mac & 0xFFFF);
  Serial.printf("Mi ID (de la MAC): %04X\n", miId);

  Serial.printf("Pines: SCK=%d MISO=%d MOSI=%d NSS=%d RST=%d DIO0=%d\n",
                PIN_SCK, PIN_MISO, PIN_MOSI, PIN_NSS, PIN_RST, PIN_DIO0);

  SPI.begin(PIN_SCK, PIN_MISO, PIN_MOSI, -1);
  LoRa.setPins(PIN_NSS, PIN_RST, PIN_DIO0);

  if (!LoRa.begin(FRECUENCIA)) {
    Serial.println();
    Serial.println(F("############################################################"));
    Serial.println(F("#  ERROR: el SX1278 no arranca                              #"));
    Serial.println(F("############################################################"));
    Serial.println(F("Los pines de arriba estan mal, o el modulo no tiene 3.3V."));
    Serial.println(F("Volve al TEST 2 y corre el escaneo."));
    while (true) { blink(1, 100); delay(700); }
  }

  LoRa.setTxPower(txPower, PA_OUTPUT_PA_BOOST_PIN);   // el Ra-02 usa PA_BOOST
  LoRa.setSpreadingFactor(sf);
  LoRa.setSignalBandwidth(125E3);
  LoRa.setCodingRate4(5);
  LoRa.setPreambleLength(8);
  LoRa.setSyncWord(SYNC_WORD);
  LoRa.enableCrc();
  LoRa.receive();

  Serial.println();
  Serial.println(F(">>> SX1278 INICIALIZADO OK <<<"));
  Serial.printf("    %.1f MHz | SF%d | BW 125 kHz | CR 4/5 | %d dBm | sync 0x%02X\n",
                FRECUENCIA / 1e6, sf, txPower, SYNC_WORD);
  Serial.println();
  Serial.println(F("Arranco como RESPONDEDOR (escucho y contesto)."));
  Serial.println(F("Manda 'a' para que ESTA placa sea la que manda PING."));
  ayuda();

  blink(3, 120);
  Serial.print(F("\n> "));
}

// -------------------------------------------------------------- recepcion

void procesarPaquete(int tam) {
  String msg = "";
  while (LoRa.available()) msg += (char)LoRa.read();

  int rssi = LoRa.packetRssi();
  float snr = LoRa.packetSnr();
  long ferr  = LoRa.packetFrequencyError();

  String tipo = campo(msg, 0);
  String src  = campo(msg, 1);
  String nseq = campo(msg, 2);

  blink(1, 30);

  if (tipo == "PING" && rol == RESPONDEDOR) {
    Serial.printf("[RX] PING de %s  seq=%s  RSSI=%d dBm  SNR=%.1f dB  dErr=%ld Hz\n",
                  src.c_str(), nseq.c_str(), rssi, snr, ferr);
    delay(30);   // pequena espera para que el otro alcance a pasar a RX
    String r = "PONG;" + String(miId, HEX) + ";" + nseq + ";" +
               String(rssi) + ";" + String(snr, 1);
    enviar(r);
    Serial.printf("[TX] PONG a %s  seq=%s\n", src.c_str(), nseq.c_str());
  }
  else if (tipo == "PONG" && rol == EMISOR) {
    contestados++;
    esperandoPong = false;
    unsigned long rtt = millis() - tEnvio;

    rssiAcum += rssi; rssiN++;
    if (rssi > rssiMejor) rssiMejor = rssi;
    if (rssi < rssiPeor)  rssiPeor  = rssi;

    Serial.printf("  <- PONG de %s  seq=%s | ida: RSSI %s dBm SNR %s dB | vuelta: RSSI %d dBm SNR %.1f dB | RTT %lu ms\n",
                  src.c_str(), nseq.c_str(),
                  campo(msg, 3).c_str(), campo(msg, 4).c_str(),
                  rssi, snr, rtt);

    if (enviados % 10 == 0) {
      Serial.printf("     [%lu/%lu recibidos, %.0f%% de perdida]\n",
                    (unsigned long)contestados, (unsigned long)enviados,
                    100.0 * (enviados - contestados) / (float)enviados);
    }
  }
  else if (tipo == "PING" && rol == EMISOR) {
    Serial.printf("[RX] PING de otro emisor (%s). Hay 2 placas en modo 'a'.\n", src.c_str());
  }
  else {
    Serial.printf("[RX] paquete raro (%d bytes): %s\n", tam, msg.c_str());
  }
}

// ------------------------------------------------------------------- comandos

void comandos() {
  if (!Serial.available()) return;
  String cmd = Serial.readStringUntil('\n');
  cmd.trim();
  if (cmd.length() == 0) return;

  char c = cmd.charAt(0);

  if (c == 'a') {
    rol = EMISOR;
    Serial.println(F("\n>>> Ahora soy EMISOR. Empiezo a mandar PING."));
    Serial.println(F(">>> ASEGURATE DE TENER ANTENA CONECTADA."));
    tUltimoPing = 0;
  }
  else if (c == 'b') {
    rol = RESPONDEDOR;
    LoRa.receive();
    Serial.println(F("\n>>> Ahora soy RESPONDEDOR. Escucho y contesto."));
  }
  else if (c == 's') estadisticas();
  else if (c == 'z') {
    enviados = contestados = 0; rssiAcum = 0; rssiN = 0;
    rssiMejor = -200; rssiPeor = 0;
    Serial.println(F("Estadisticas borradas."));
  }
  else if (c == 't') {
    int n = cmd.substring(1).toInt();
    if (n < 2 || n > 17) Serial.println(F("Potencia valida con PA_BOOST: 2 a 17 dBm."));
    else {
      txPower = n;
      LoRa.setTxPower(txPower, PA_OUTPUT_PA_BOOST_PIN);
      Serial.printf("Potencia TX = %d dBm\n", txPower);
      if (n > 10) Serial.println(F("OJO: con las placas a menos de 1 m esto satura el RX."));
    }
  }
  else if (c == 'f') {
    int n = cmd.substring(1).toInt();
    if (n < 7 || n > 12) Serial.println(F("SF valido: 7 a 12. SF alto = mas alcance, mas lento."));
    else {
      sf = n;
      LoRa.setSpreadingFactor(sf);
      LoRa.receive();
      Serial.printf("SF = %d  (acordate de ponerlo IGUAL en las otras placas)\n", sf);
    }
  }
  else if (c == 'r') pisoDeRuido();
  else if (c == 'd') {
    if (!cazandoDio0) iniciarCazaDio0();
    else              reporteDio0();
  }
  else ayuda();

  Serial.print(F("\n> "));
}

// ----------------------------------------------------------------------- loop

void loop() {
  comandos();

  muestrearDio();                  // antes de parsePacket: ahi vive el pulso
  int tam = LoRa.parsePacket();
  if (tam > 0) procesarPaquete(tam);

  if (rol == EMISOR && millis() - tUltimoPing >= PERIODO_PING) {
    tUltimoPing = millis();

    if (esperandoPong) {
      Serial.printf("  !! seq=%lu SIN RESPUESTA (timeout de %d ms)\n",
                    (unsigned long)seq, TIMEOUT_PONG);
    }

    seq++;
    enviados++;
    String m = "PING;" + String(miId, HEX) + ";" + String(seq);
    Serial.printf("-> PING seq=%lu ...\n", (unsigned long)seq);
    enviar(m);
    tEnvio = millis();
    esperandoPong = true;
  }

  delay(2);
}

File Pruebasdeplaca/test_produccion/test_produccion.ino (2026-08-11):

/*
 * ============================================================================
 *  TEST DE PRODUCCION - Placa ESP32-C3-WROOM-02 + SX1278 (433 MHz)
 *  Revision de placa: Version2
 * ============================================================================
 *
 *  Corre 14 pruebas solo y da un veredicto: APROBADA o RECHAZADA.
 *  No tiene comandos. Flasheas, apretas RESET, y leer el resultado.
 *  Cada falla te dice que medir.
 *
 *  DURACION: ~25 segundos por placa.
 *
 * ----------------------------------------------------------------------------
 *  DOS MODOS, se eligen con el boton BOOT al arrancar
 * ----------------------------------------------------------------------------
 *
 *  MODO TEST (normal)
 *      Arrancar sin tocar nada y esperar 3 segundos. Corre las 14 pruebas.
 *
 *  MODO BALIZA (una sola placa, la "patron")
 *      Al arrancar hay una ventana de 3 segundos, avisada por el serial.
 *      Apretar BOOT, o escribir  b  y ENTER en el Monitor. Cualquiera sirve.
 *
 *      QUEDA GUARDADO EN FLASH. Podes desconectar el TTL y alimentarla aparte:
 *      va a arrancar como baliza sola cada vez, sin que le digas nada.
 *
 *      Para devolverla a modo test: apretar BOOT o escribir  t  en la ventana.
 *      (Tambien se borra flasheando con "Erase All Flash Before Upload".)
 *
 *      La placa queda contestando pings para siempre. Dejala encendida en el
 *      banco: es contra ella que se prueba el enlace de radio de las demas.
 *
 *      OJO: la baliza tiene que estar a 5-10 cm de la placa bajo prueba
 *      mientras no haya antenas. A 50 cm el enlace queda en el limite de
 *      sensibilidad y el test 14 falla al azar en placas buenas.
 *
 *      Sin baliza el test corre igual, pero la prueba 14 queda SALTEADA y el
 *      veredicto lo aclara. El enlace de RF es lo unico que una placa no puede
 *      verificar sola.
 *
 * ----------------------------------------------------------------------------
 *  FLUJO PARA UN LOTE
 * ----------------------------------------------------------------------------
 *      1. Preparar UNA placa patron en modo baliza. Se hace una sola vez
 *      2. Por cada placa: conectar TTL -> flashear -> RESET -> leer veredicto
 *      3. Copiar la linea que empieza con CSV, a la planilla
 *
 *  ANTENA: el test transmite 3 paquetes cortos a 2 dBm. Sin antena el riesgo
 *  al amplificador es bajo a esa potencia. Si tenes antenas, mejor ponerlas.
 *
 *  ARDUINO IDE: ESP32C3 Dev Module | USB CDC On Boot = Disabled | 115200
 *  LIBRERIA: "LoRa" de Sandeep Mistry
 * ============================================================================
 */

#include <SPI.h>
#include <LoRa.h>
#include <WiFi.h>
#include <Preferences.h>
#include "esp_system.h"

Preferences prefs;   // guarda el modo baliza en flash, sobrevive al corte de energia

// ------------------------------------------------------------------- pines
#define PIN_SCK      10
#define PIN_MISO      6
#define PIN_MOSI      7
#define PIN_NSS       8
#define PIN_RST       5
#define PIN_DIO0      4
#define PIN_BOOTBTN   0     // el boton BOOT. Sirve para elegir el modo baliza

// --------------------------------------------------------------- parametros
#define FRECUENCIA        433E6
#define SYNC_WORD         0x34
#define TX_POWER          2       // dBm. NO subir sin antena
#define MIN_REDES_WIFI    1
#define RSSI_ENLACE_MIN   -125    // por debajo de esto el enlace no sirve

// registros del SX127x
#define REG_FIFO_ADDR_PTR 0x0D
#define REG_FRF_MSB       0x06
#define REG_IRQ_FLAGS     0x12
#define REG_VERSION       0x42
#define IRQ_TX_DONE       0x08
#define SX127X_VERSION    0x12

// ------------------------------------------------------------------ estado
#define N_TESTS 14
struct Resultado {
  const char *nombre;
  int  estado;          // 0 = falla, 1 = ok, 2 = salteado
  char detalle[40];
  const char *ayuda;
};
Resultado R[N_TESTS];
int idx = 0;

char macStr[20] = "";
int  wifiRedes = 0, wifiMejorRssi = -200, enlaceRssi = -200, pisoRuido = 0;
uint32_t flashSize = 0;

volatile bool txDoneFlag = false;
void IRAM_ATTR onTxDoneISR() { txDoneFlag = true; }

// --------------------------------------------------------------- utilidades

void anota(const char *nombre, int estado, const char *detalle, const char *ayuda) {
  if (idx >= N_TESTS) return;
  R[idx].nombre = nombre;
  R[idx].estado = estado;
  snprintf(R[idx].detalle, sizeof(R[idx].detalle), "%s", detalle);
  R[idx].ayuda = ayuda;
  const char *m = (estado == 1) ? "OK" : (estado == 2) ? "SALTEADO" : "FALLA";
  Serial.printf("[%02d] %-32s %-22s %s\n", idx + 1, nombre, detalle, m);
  if (estado == 0 && ayuda) Serial.printf("     -> %s\n", ayuda);
  idx++;
}

// SPI crudo, antes de que la libreria tome el control
uint8_t leerReg(uint8_t addr) {
  SPI.beginTransaction(SPISettings(1000000, MSBFIRST, SPI_MODE0));
  digitalWrite(PIN_NSS, LOW);  delayMicroseconds(2);
  SPI.transfer(addr & 0x7F);
  uint8_t v = SPI.transfer(0x00);
  digitalWrite(PIN_NSS, HIGH); SPI.endTransaction();
  delayMicroseconds(2);
  return v;
}

void escribirReg(uint8_t addr, uint8_t val) {
  SPI.beginTransaction(SPISettings(1000000, MSBFIRST, SPI_MODE0));
  digitalWrite(PIN_NSS, LOW);  delayMicroseconds(2);
  SPI.transfer(addr | 0x80);
  SPI.transfer(val);
  digitalWrite(PIN_NSS, HIGH); SPI.endTransaction();
  delayMicroseconds(2);
}

// Espera hasta 3 s a que pase alguna de estas dos cosas:
//   - se aprieta el boton BOOT
//   - llega la letra indicada por el puerto serie
// Devuelve true si ocurrio alguna. Imprime puntos como cuenta regresiva.
bool esperarEntrada(char letra) {
  unsigned long t0 = millis();
  int puntos = 0;
  while (millis() - t0 < 3000) {
    if (digitalRead(PIN_BOOTBTN) == LOW) return true;
    if (Serial.available()) {
      char c = Serial.read();
      if (c == letra || c == (char)(letra - 32)) return true;   // acepta mayuscula
    }
    if ((int)((millis() - t0) / 500) > puntos) { puntos++; Serial.print('.'); }
    delay(10);
  }
  return false;
}

// =========================================================== MODO BALIZA
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

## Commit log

2026-05-06 Primera prueba de la PCB
    [PrimerPrueba.kicad_pcb, PrimerPrueba.kicad_sch]
2026-05-06 Id de los componentes listo
    [PrimerPrueba.kicad_sch]
2026-05-06 botones agregados
    [PrimerPrueba.kicad_pcb, PrimerPrueba.kicad_sch]
2026-05-30 correctiones con codigo de componente
    [PrimerPrueba.kicad_pcb, PrimerPrueba.kicad_sch]
2026-08-11 placas v2 probadas
    [PrimerPrueba.kicad_pcb, PrimerPrueba.kicad_sch, Version2.kicad_pcb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]
